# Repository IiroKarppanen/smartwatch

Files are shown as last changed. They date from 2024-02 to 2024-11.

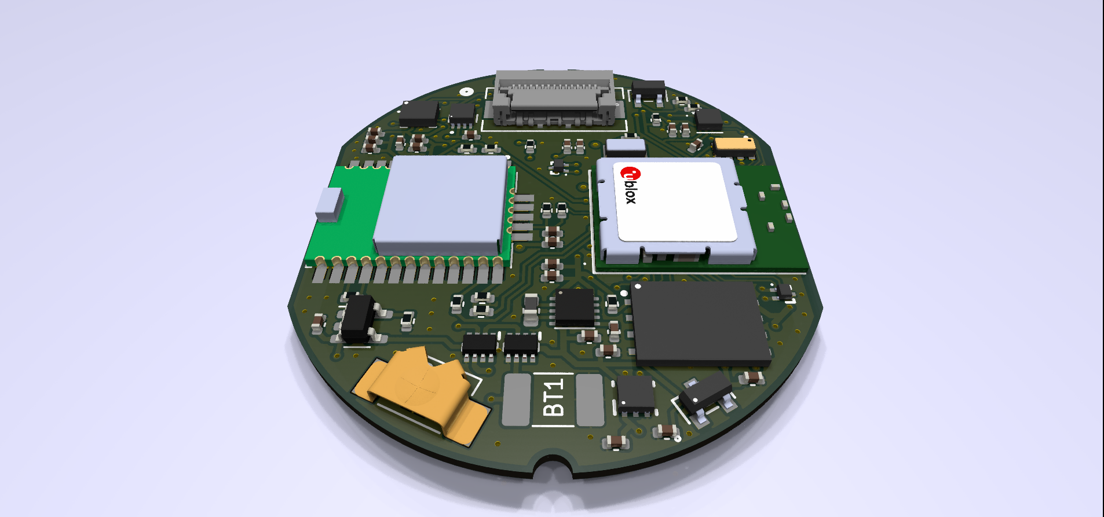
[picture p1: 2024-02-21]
Hardware/docs/render.png

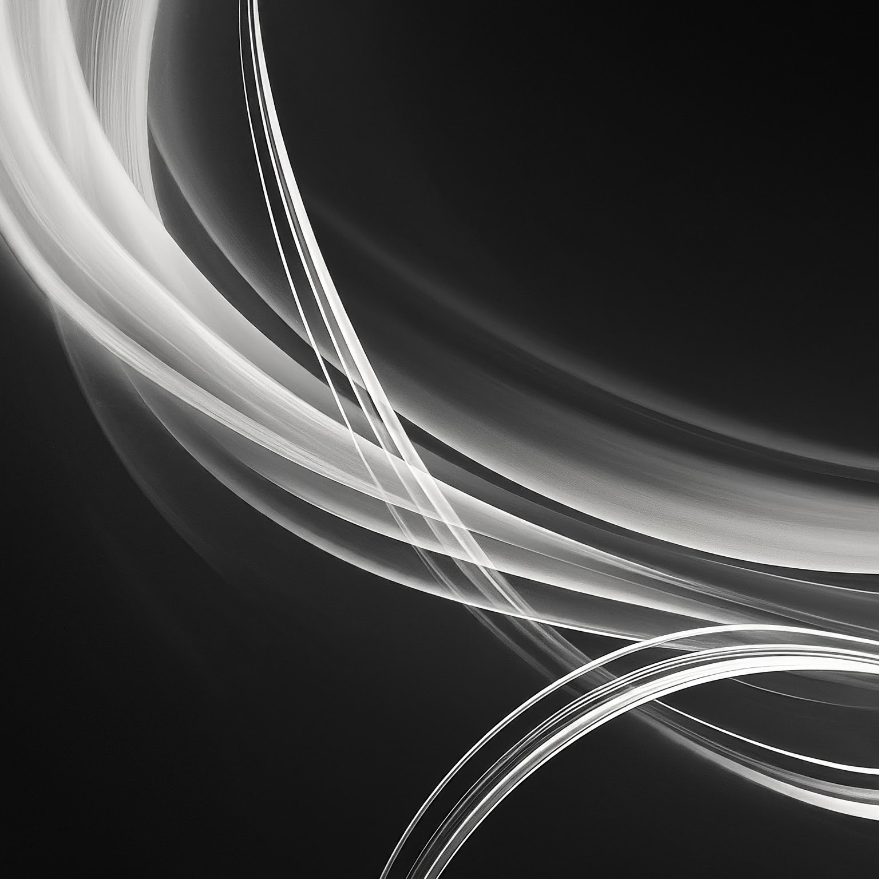
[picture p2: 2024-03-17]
Software/assets/image_fx_abstract_white_lines_over_black_background.jpg

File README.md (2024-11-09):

## Features
- nRF5340 SoC
- 240x240 LCD display
- Pulseoximetry
- GNSS
- Accelometer & Gyroscope
- Accurate RTC with backup battery

Näyttökuva 2024-11-07 140855

Näyttökuva 2024-11-07 140938

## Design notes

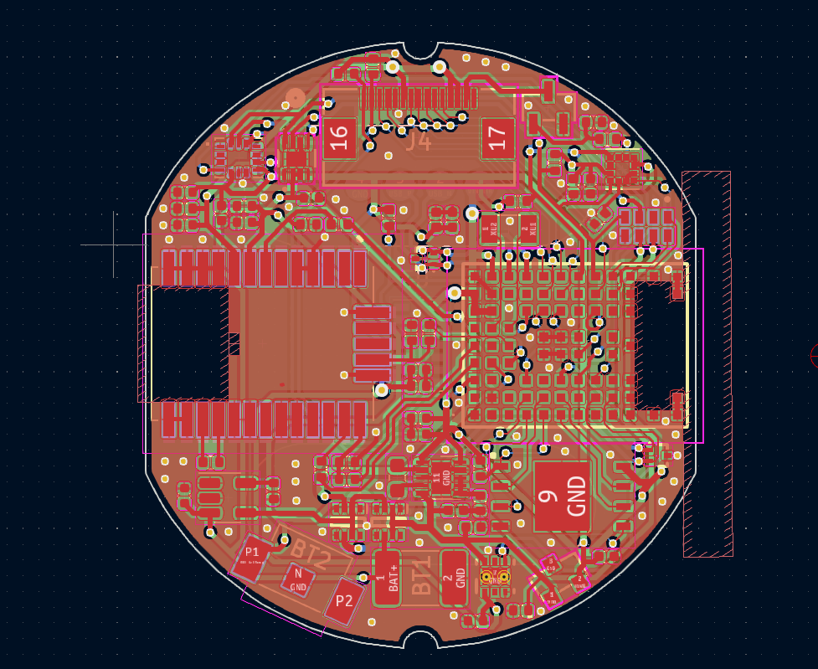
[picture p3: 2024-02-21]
Hardware/docs/pcb_view.png

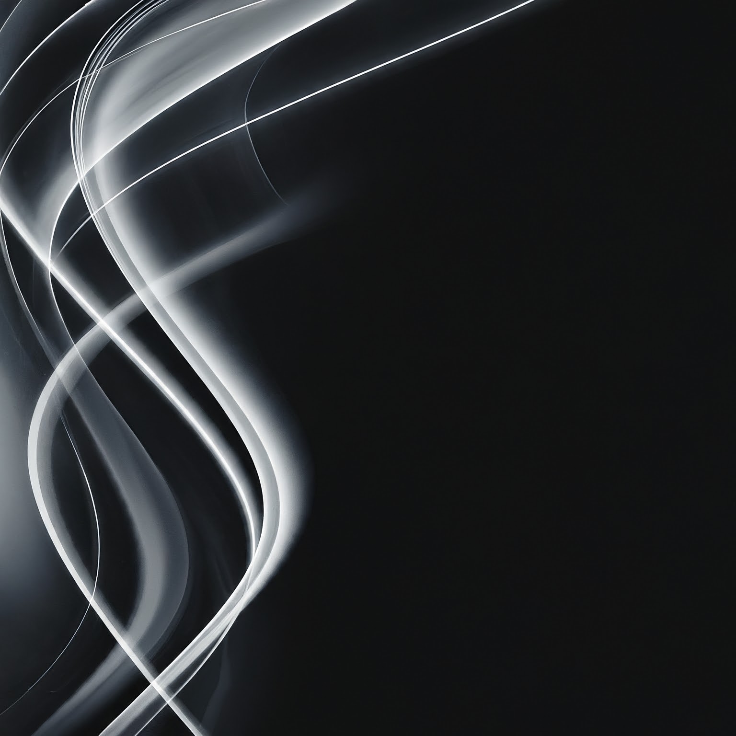
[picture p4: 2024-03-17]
Software/assets/image_fx_abstract_white_lines_over_black_background (1).jpg

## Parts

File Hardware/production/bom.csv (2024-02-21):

Designator | Footprint | Quantity | Value | LCSC Part #
BT1 | 1812 | 1 | Battery_Cell
BT2 | BAT_2994TR | 1 | 2994TR
C1, C10, C4, C6, C9 | 0402 | 5 | 10uF
C11, C13, C14 | 0402 | 3 | 100n
C12 | 0402 | 1 | 220nF
C15, C17 | 0402 | 2 | 100nF
C16, C22, C23 | 0402 | 3 | 1uF
C18, C2, C5, C8 | 0402 | 4 | 0.1uF
C19, C20, C7 | 0402 | 3 | 4.7uF
C21 | 0402 | 1 | 2.2uF
C3 | 0402 | 1 | 10u
IC1 | SON127P800X600X80-9N-D | 1 | W25Q256JVEIQ
IC2 | NORAB12000B | 1 | NORA-B120-00B
IC3, IC4 | SOTFL50P160X60-8N | 2 | LM66200DRLR
J1, J2 | Pogo_Female_4Pin | 2 | Conn_01x04
J4 | CONN_X05A20L15T_XKB | 1 | X05A20L15T
L2 | 0603 | 1 | MBKK1608T1R5M
MOSFET1 | SOT-23TO-236_318-08_ONS | 1 | 2N7002
R1 | 0402 | 1 | 100k | NRF52840-QIAA-R
R10, R12, R15, R16, R9 | 0402 | 5 | 4.7k | NRF52840-QIAA-R
R11 | 0402 | 1 | 1M
R13, R4, R6, R7 | 0402 | 4 | 1k
R14, R5, R8 | 0402 | 3 | 5k6
R17 | 0402 | 1 | 5.1k
R18 | 0805 | 1 | 470
R2 | 0402 | 1 | 0R
R3 | 0402 | 1 | 10k
U1 | 21-0168E_T822-3_MXM | 1 | MAX17048G+T10
U10 | IC_RV-3028-C7_32.768KHZ_1PPM-TA-QC | 1 | RV-3028-C7_32.768KHZ_1PPM-TA-QC
U11 | SOT-23-5 | 1 | MCP73831T-2ACI/OT | MCP73831-2-OT
U12 | DRV0006A | 1 | TPS70950QDRVRQ1
U2, U9 | DRT0003A | 2 | TPD2EUSB30DRTR
U3 | MAX30101EFD_T | 1 | MAX30101EFD_T
U4 | WSON-10-1EP_2.5x2.5mm_P0.5mm_EP1.2x2mm | 1 | TPS63031DSK
U5 | XCVR_L96-M33 | 1 | L96-M33
U6 | SOT-23_DIO | 1 | AP7313-18SAG-7
U7 | XDCR_BMI270 | 1 | BMI270
U8 | PQFN50P200X200X70-12N | 1 | LIS2MDLTR
X2 | Crystal_SMD_3215-2Pin_3.2x1.5mm | 1 | 9HT10-32.768KBZC-T

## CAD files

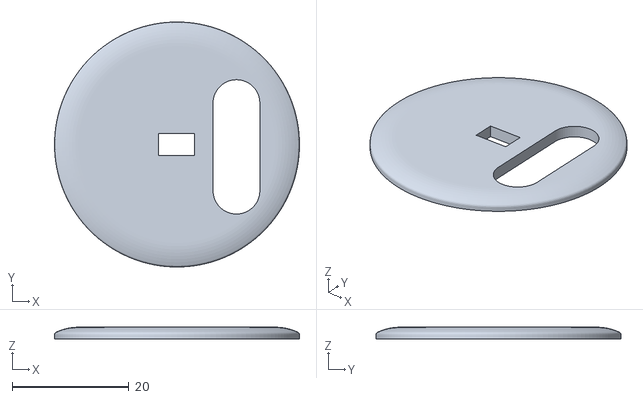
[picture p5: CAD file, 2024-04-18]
Hardware/docs/cover.stl
42.0 x 42.0 x 2.00

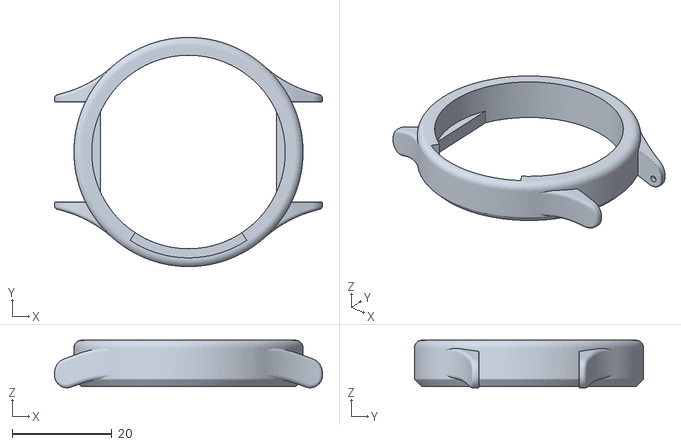
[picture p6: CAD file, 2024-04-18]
Hardware/docs/watch_S_holes.stl
53.8 x 46.0 x 9.57

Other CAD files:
Hardware/docs/watch_L_holes.stl

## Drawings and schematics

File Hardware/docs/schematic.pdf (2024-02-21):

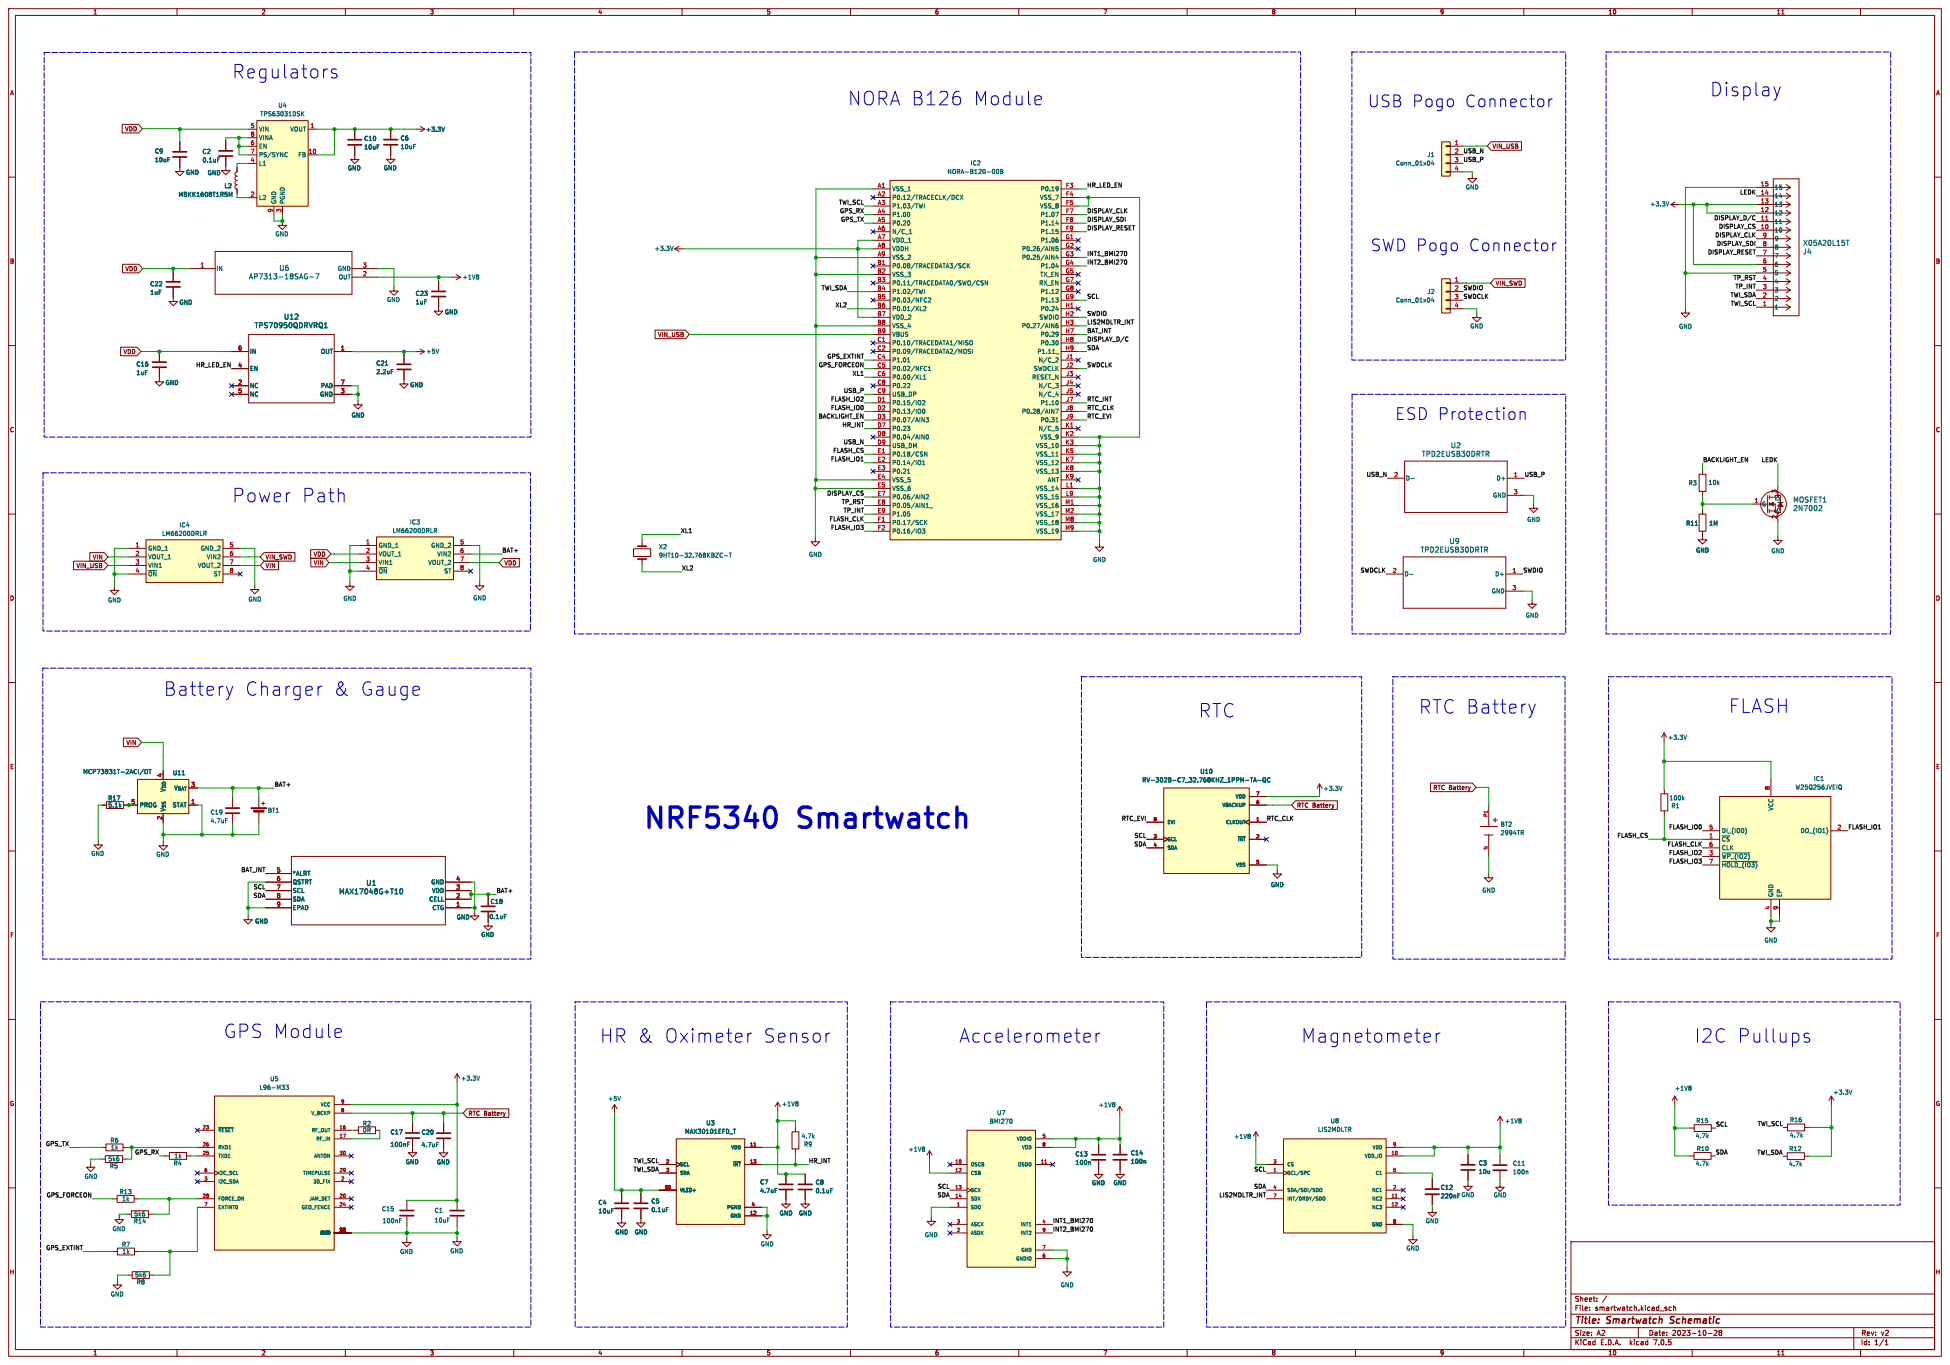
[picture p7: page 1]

NORA B126 Module
VSS_1 A1 P0.12/TRACECLK/DCX A2 P1.03/TWI A3 P1.00 A4 P0.20 A5 N/C_1 A6 VDD_1 A7 VDDH A8 VSS_2 A9 P0.08/TRACEDATA3/SCK B1 VSS_3 B2 P0.11/TRACEDATA0/SWO/CSN B3 P1.02/TWI B4 P0.03/NFC2 B5 P0.01/XL2 B6 VDD_2 B7 VSS_4 B8 VBUS B9 P0.10/TRACEDATA1/MISO C1 P0.09/TRACEDATA2/MOSI C2 P1.01 C4 P0.02/NFC1 C5 P0.00/XL1 C6 P0.22 C8 USB_DP C9 P0.15/IO2 D1 P0.13/IO0 D2 P0.07/AIN3 D3 P0.23 D7 P0.04/AIN0 D8 USB_DM D9 P0.18/CSN E1 P0.14/IO1 E2 P0.21 E3 VSS_5 E4 VSS_6 E5 P0.06/AIN2 E7 P0.05/AIN1_ E8 P1.05 E9 P0.17/SCK F1 P0.16/IO3 F2

File: smartwatch.kicad_sch Sheet: / GND

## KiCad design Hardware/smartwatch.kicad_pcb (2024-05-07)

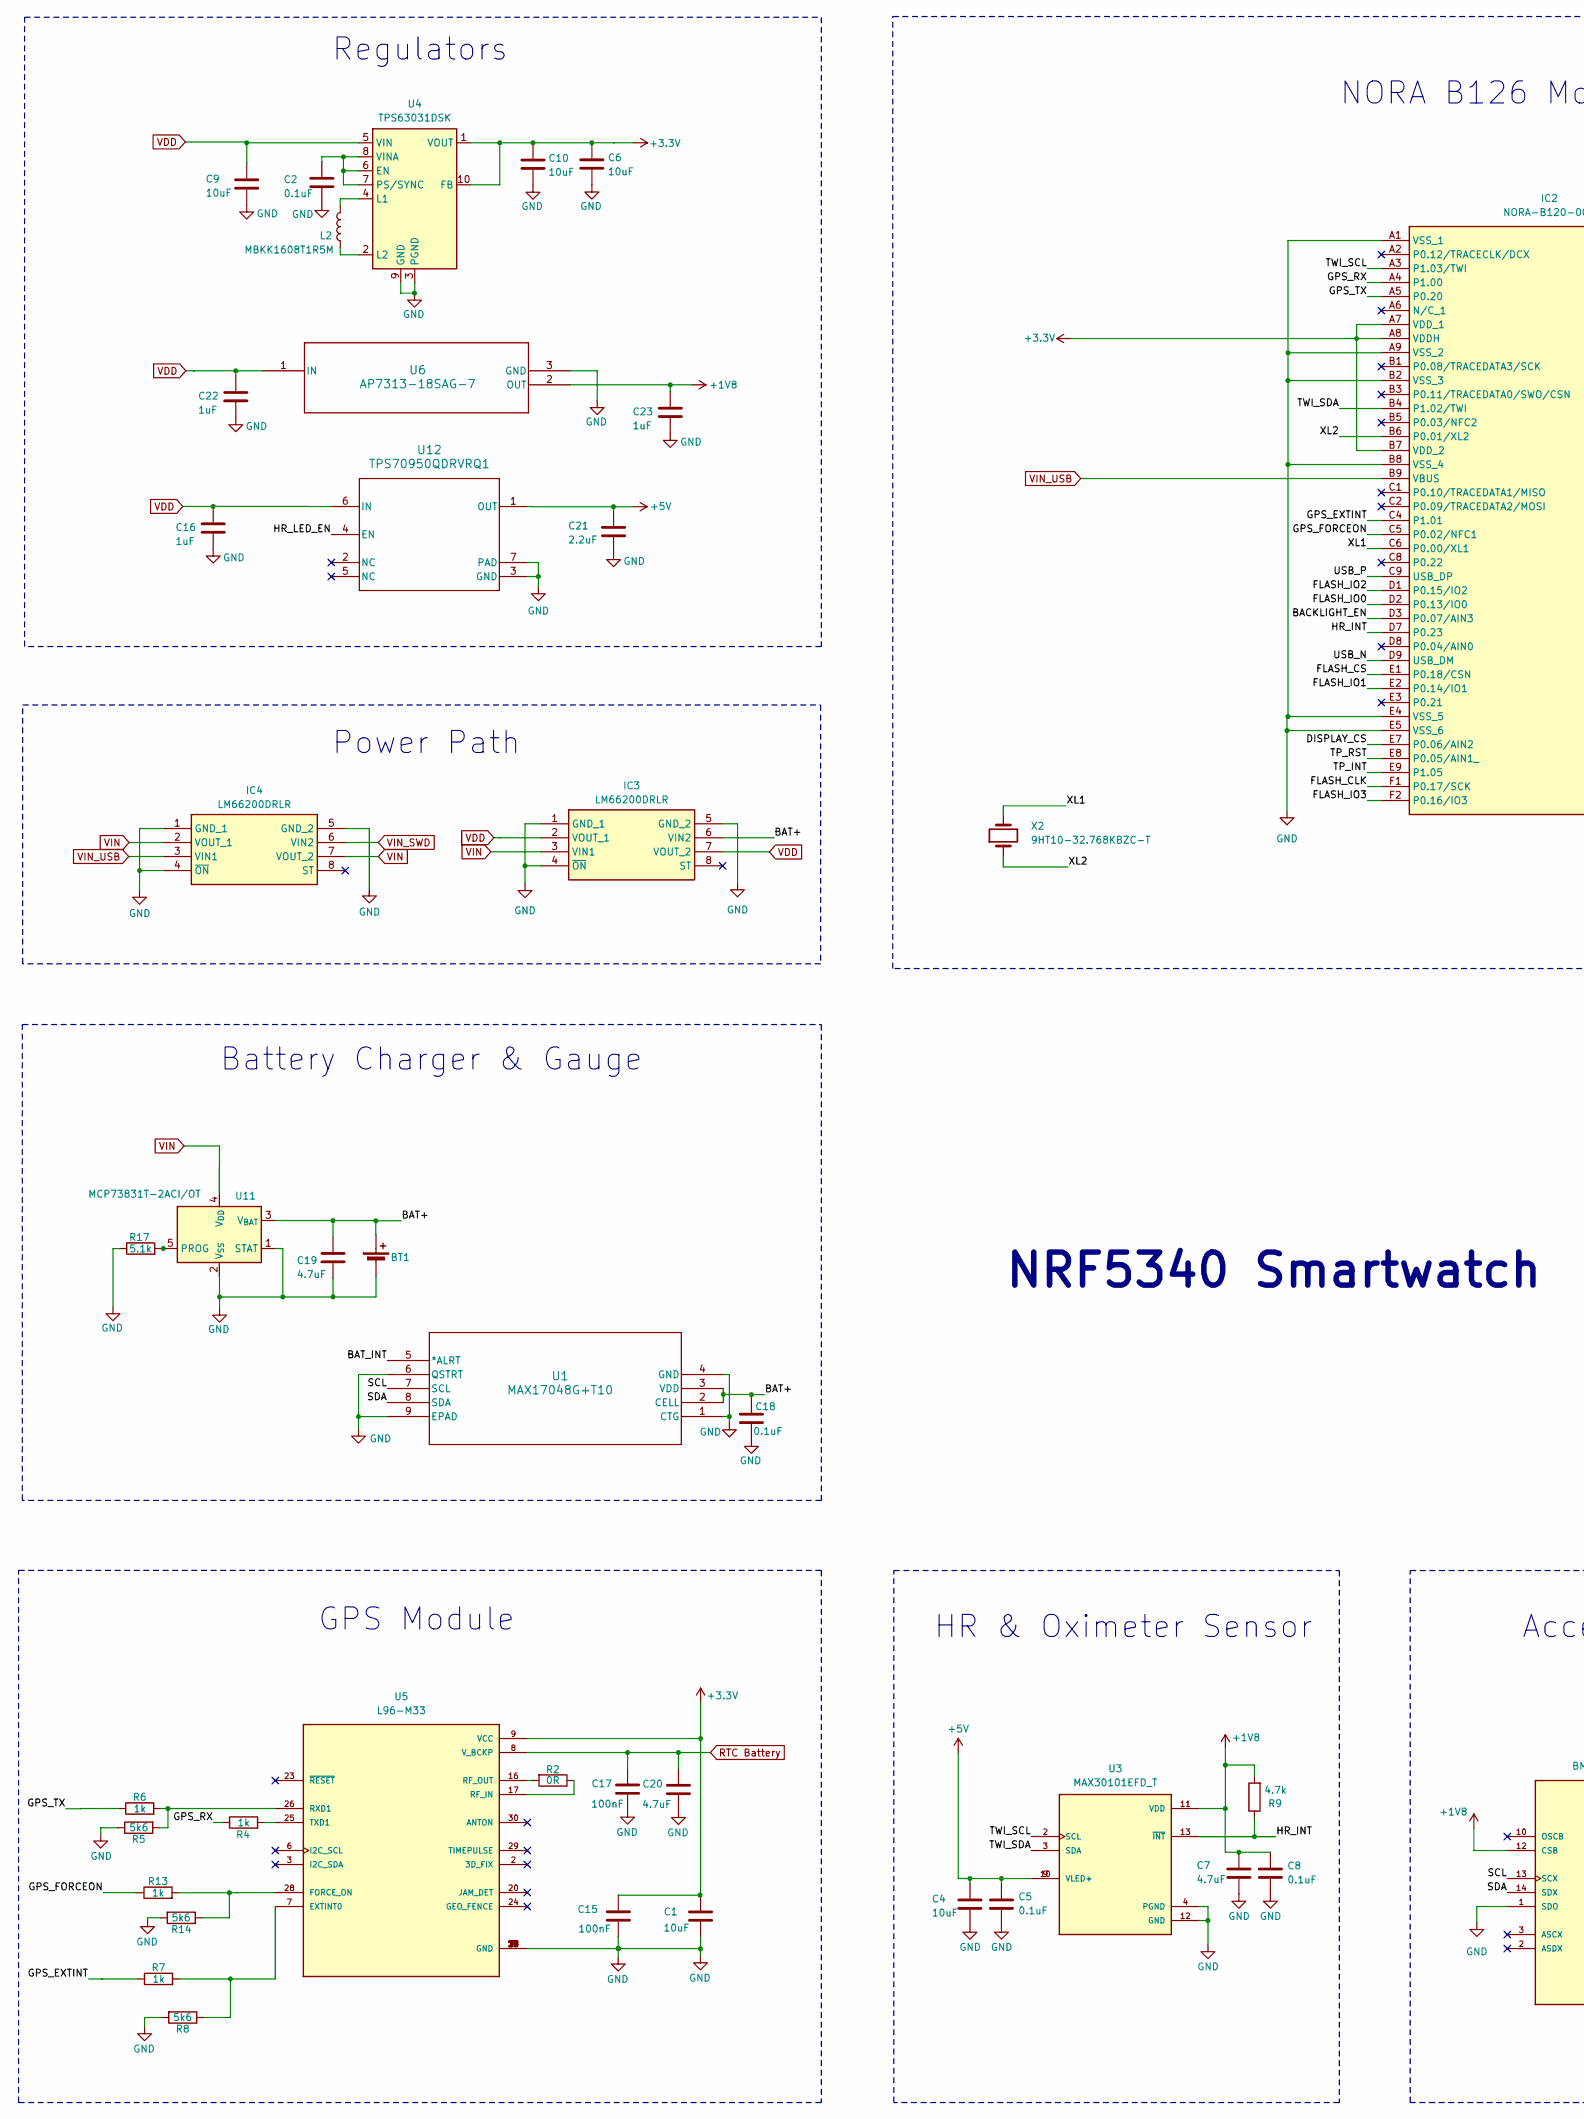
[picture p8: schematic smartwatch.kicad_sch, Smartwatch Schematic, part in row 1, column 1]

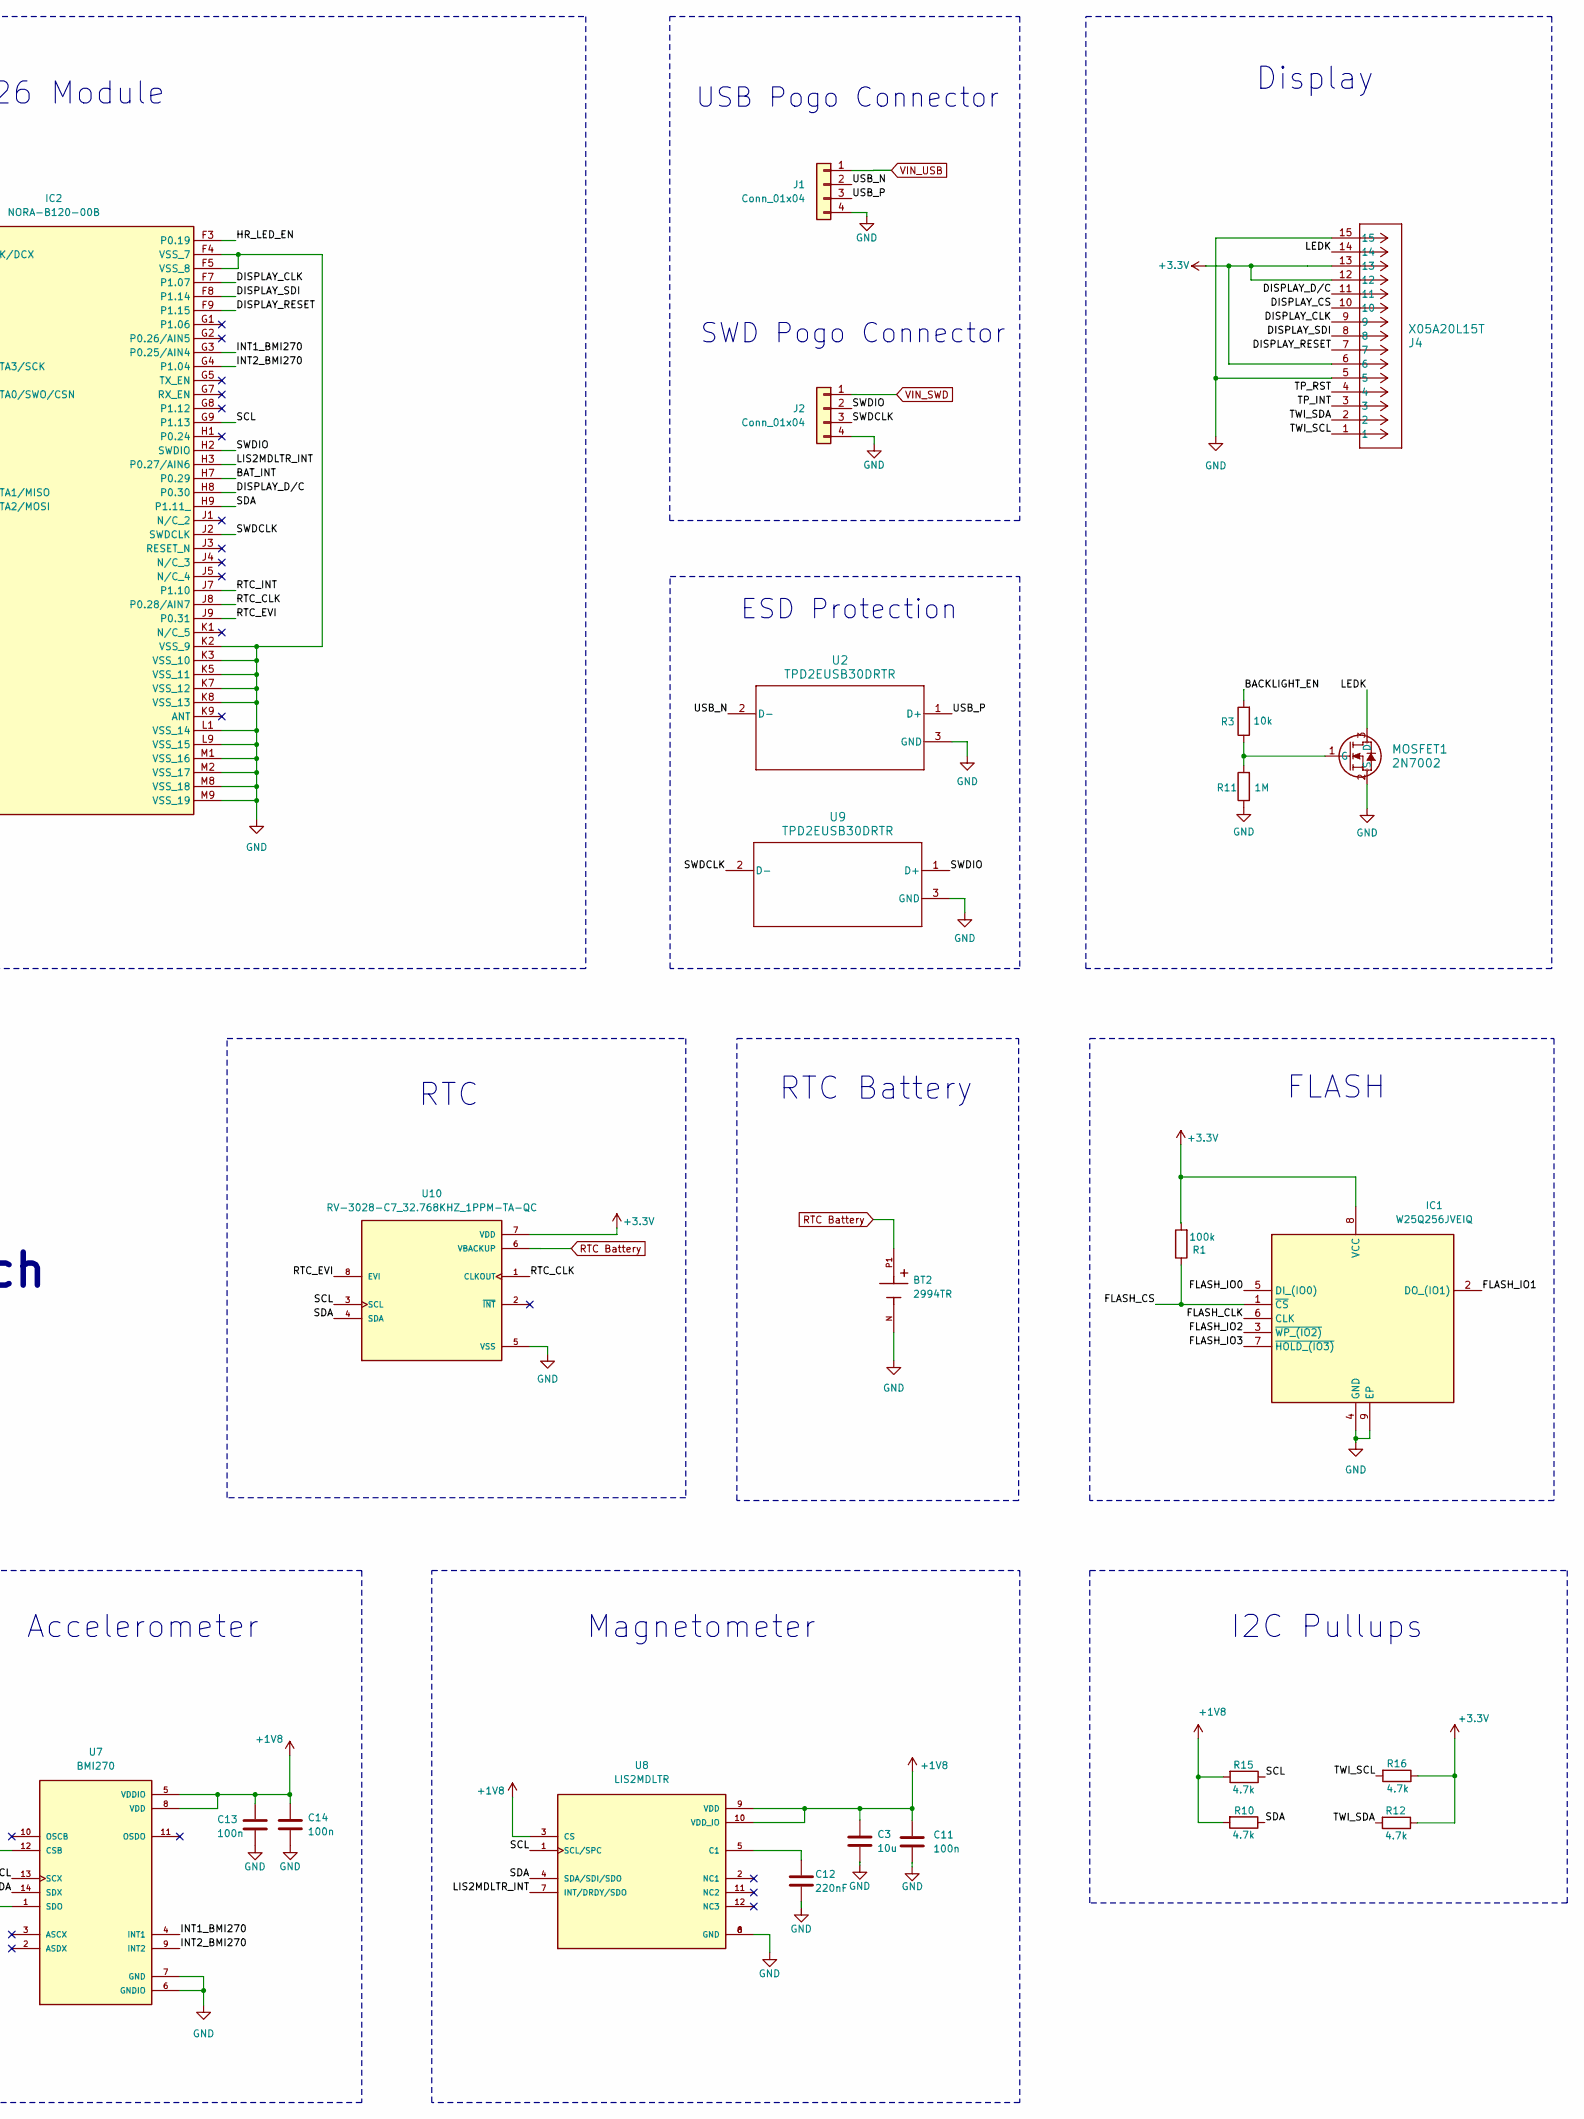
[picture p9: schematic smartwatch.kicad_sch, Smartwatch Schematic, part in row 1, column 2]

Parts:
BT1: Battery_Cell; C_1812_4532Metric_Pad1.57x3.40mm_HandSolder
BT2: 2994TR; BAT_2994TR; PARTREV E
C1, C4, C6, C9, C10: 10uF; C_0402_1005Metric
C2, C5, C8, C18: 0.1uF; C_0402_1005Metric
C3: 10u; C_0402_1005Metric
C7, C19, C20: 4.7uF; C_0402_1005Metric
C11, C13, C14: 100n; C_0402_1005Metric
C12: 220nF; C_0402_1005Metric
C15, C17: 100nF; C_0402_1005Metric
C16, C22, C23: 1uF; C_0402_1005Metric
C21: 2.2uF; C_0402_1005Metric
IC1: W25Q256JVEIQ; SON127P800X600X80-9N-D; Mouser Part Number 454-W25N01GVZEIGTR
IC2: NORA-B120-00B; NORAB12000B; Mouser Part Number 377-NORA-B120-00B
IC3, IC4: LM66200DRLR; SOTFL50P160X60-8N; Mouser Part Number 595-LM66200DRLR
J1, J2: Conn_01x04; Pogo_Female_4Pin
J4: X05A20L15T; CONN_X05A20L15T_XKB
L2: MBKK1608T1R5M; L_0603_1608Metric
MOSFET1: 2N7002; SOT-23TO-236_318-08_ONS
R1: 100k; R_0402_1005Metric; MPN NRF52840-QIAA-R
R2: 0R; R_0402_1005Metric
R3: 10k; R_0402_1005Metric
R4, R6, R7, R13: 1k; R_0402_1005Metric
R5, R8, R14: 5k6; R_0402_1005Metric
R9, R10, R12, R15, R16: 4.7k; R_0402_1005Metric; MPN NRF52840-QIAA-R
R11: 1M; R_0402_1005Metric
R17: 5.1k; R_0402_1005Metric
U1: MAX17048G+T10; 21-0168E_T822-3_MXM
U2, U9: TPD2EUSB30DRTR; DRT0003A
U3: MAX30101EFD_T; PARTREV 2
U4: TPS63031DSK; WSON-10-1EP_2.5x2.5mm_P0.5mm_EP1.2x2mm
U5: L96-M33; XCVR_L96-M33; DigiKey_Part_Number 2958-L96-M33TR-ND
U6: AP7313-18SAG-7; SOT-23_DIO
U7: BMI270; XDCR_BMI270
U8: LIS2MDLTR; PQFN50P200X200X70-12N; PARTREV Rev 5
U10: RV-3028-C7_32.768KHZ_1PPM-TA-QC; IC_RV-3028-C7_32.768KHZ_1PPM-TA-QC; PARTREV 1.3
U11: MCP73831T-2ACI/OT; SOT-23-5; MPN MCP73831-2-OT
U12: TPS70950QDRVRQ1; DRV0006A
X2: 9HT10-32.768KBZC-T; Crystal_SMD_3215-2Pin_3.2x1.5mm

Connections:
+1V8: C3.1, C7.1, C8.1, C11.1, C13.1, C14.1, C23.1, R9.2, R10.2, R15.2, U3.11 (VDD), U6.2 (OUT), U7.5 (VDDIO), U7.8 (VDD), U7.12 (CSB), U8.3 (CS), U8.9 (VDD), U8.10 (VDD_IO)
+3.3V: C1.1, C6.1, C10.1, C15.1, IC1.8 (VCC), IC2.A7 (VDD_1), IC2.A8 (VDDH), IC2.B7 (VDD_2), J4.6, J4.12, J4.13, R1.2, R12.1, R16.1, U4.1 (VOUT), U4.10 (FB), U5.9 (VCC), U10.7 (VDD)
+5V: C4.1, C5.1, C21.1, U3.9 (VLED+), U3.10 (VLED+), U12.1 (OUT)
/BACKLIGHT_EN: IC2.D3 (P0.07/AIN3), R3.2
/BAT+: BT1.1 (+), C18.1, C19.1, IC3.6 (VIN2), U1.2 (CELL), U1.3 (VDD), U11.3 (V_{BAT})
/BAT_INT: IC2.H7 (P0.29), U1.5 (*ALRT)
/DISPLAY_CLK: IC2.F7 (P1.07), J4.9
/DISPLAY_CS: IC2.E7 (P0.06/AIN2), J4.10
/DISPLAY_D/C: IC2.H8 (P0.30), J4.11
/DISPLAY_RESET: IC2.F9 (P1.15), J4.7
/DISPLAY_SDI: IC2.F8 (P1.14), J4.8
/FLASH_CLK: IC1.6 (CLK), IC2.F1 (P0.17/SCK)
/FLASH_CS: IC1.1 (~CS), IC2.E1 (P0.18/CSN), R1.1
/FLASH_IO0: IC1.5 (DI_(IO0)), IC2.D2 (P0.13/IO0)
/FLASH_IO1: IC1.2 (DO_(IO1)), IC2.E2 (P0.14/IO1)
/FLASH_IO2: IC1.3 (~WP_(IO2)), IC2.D1 (P0.15/IO2)
/FLASH_IO3: IC1.7 (~HOLD_(IO3)), IC2.F2 (P0.16/IO3)
/GPS_EXTINT: IC2.C4 (P1.01), R7.1
/GPS_FORCEON: IC2.C5 (P0.02/NFC1), R13.1
/GPS_RX: IC2.A4 (P1.00), R4.1
/GPS_TX: IC2.A5 (P0.20), R6.1
/HR_INT: IC2.D7 (P0.23), R9.1, U3.13 (~INT)
/HR_LED_EN: IC2.F3 (P0.19), U12.4 (EN)
/INT1_BMI270: IC2.G3 (P0.25/AIN4), U7.4 (INT1)
/INT2_BMI270: IC2.G4 (P1.04), U7.9 (INT2)
/LEDK: J4.14, MOSFET1.3 (D)
/LIS2MDLTR_INT: IC2.H3 (P0.27/AIN6), U8.7 (INT/DRDY/SDO)
/RTC_CLK: IC2.J8 (P0.28/AIN7), U10.1 (CLKOUT)
/RTC_EVI: IC2.J9 (P0.31), U10.8 (EVI)
/RTC_INT: IC2.J7 (P1.10)
/SCL: IC2.G9 (P1.13), R15.1, U1.7 (SCL), U7.13 (SCX), U8.1 (SCL/SPC), U10.3 (SCL)
/SDA: IC2.H9 (P1.11_), R10.1, U1.8 (SDA), U7.14 (SDX), U8.4 (SDA/SDI/SDO), U10.4 (SDA)
/SWDCLK: IC2.J2 (SWDCLK), J2.3, U9.2 (D-)
/SWDIO: IC2.H2 (SWDIO), J2.2, U9.1 (D+)
/TP_INT: IC2.E9 (P1.05), J4.3
/TP_RST: IC2.E8 (P0.05/AIN1_), J4.4
/TWI_SCL: IC2.A3 (P1.03/TWI), J4.1, R16.2, U3.2 (SCL)
/TWI_SDA: IC2.B4 (P1.02/TWI), J4.2, R12.2, U3.3 (SDA)
/USB_N: IC2.D9 (USB_DM), J1.2, U2.2 (D-)
/USB_P: IC2.C9 (USB_DP), J1.3, U2.1 (D+)
/XL1: IC2.C6 (P0.00/XL1), X2.2
/XL2: IC2.B6 (P0.01/XL2), X2.1
unnamed: MOSFET1.1 (G), R3.1, R11.2
unnamed: C2.1, U4.6 (EN), U4.7 (PS/SYNC), U4.8 (VINA)
unnamed: L2.2, U4.4 (L1)
unnamed: L2.1, U4.2 (L2)
unnamed: R13.2, R14.1, U5.28 (FORCE_ON)
unnamed: R2.1, U5.17 (RF_IN)
unnamed: R2.2, U5.16 (RF_OUT)
unnamed: R5.2, R6.2, U5.26 (RXD1)
unnamed: R4.2, U5.25 (TXD1)
unnamed: C12.1, U8.5 (C1)
unnamed: R17.2, U11.5 (PROG)
RTC Battery: BT2.P1, C17.1, C20.1, U5.8 (V_BCKP), U10.6 (VBACKUP)
VDD: C9.1, C16.1, C22.1, IC3.2 (VOUT_1), IC3.7 (VOUT_2), U4.5 (VIN), U6.1 (IN), U12.6 (IN)
VIN: IC3.3 (VIN1), IC4.2 (VOUT_1), IC4.7 (VOUT_2), U11.4 (V_{DD})
VIN_SWD: IC4.6 (VIN2), J2.1
VIN_USB: IC2.B9 (VBUS), IC4.3 (VIN1), J1.1

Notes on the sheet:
NORA B126 Module
NRF5340 Smartwatch
HR & Oximeter Sensor
Magnetometer
GPS Module
I2C Pullups
SWD Pogo Connector
RTC Battery
Battery Charger & Gauge
Display
Accelerometer
USB Pogo Connector
ESD Protection
FLASH
Power Path
RTC
Regulators

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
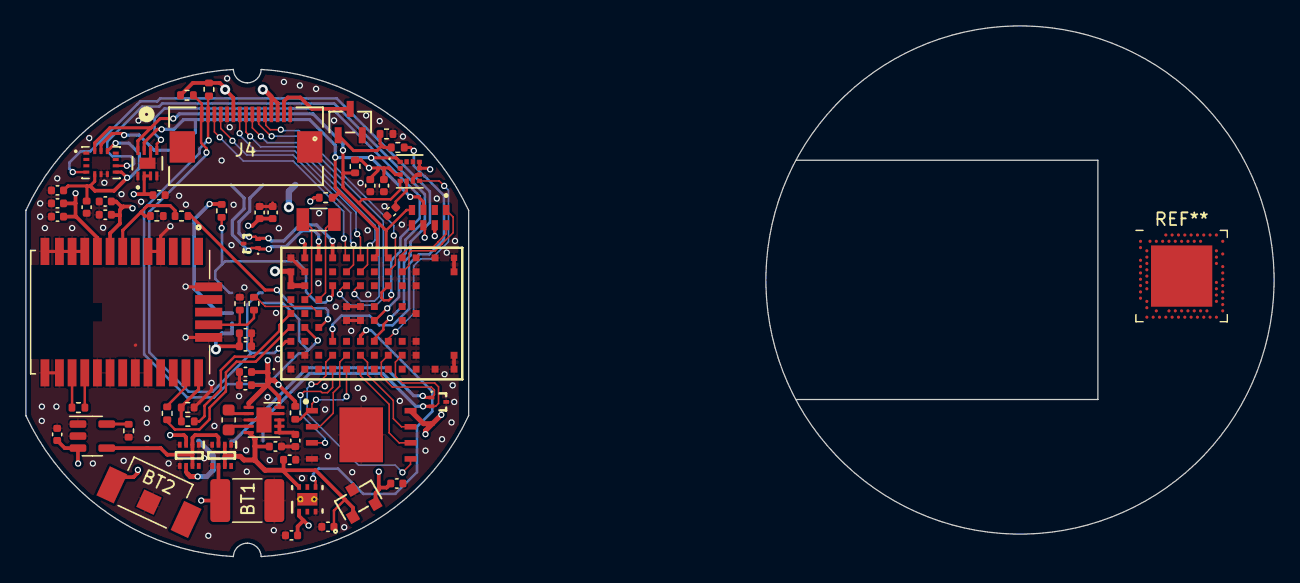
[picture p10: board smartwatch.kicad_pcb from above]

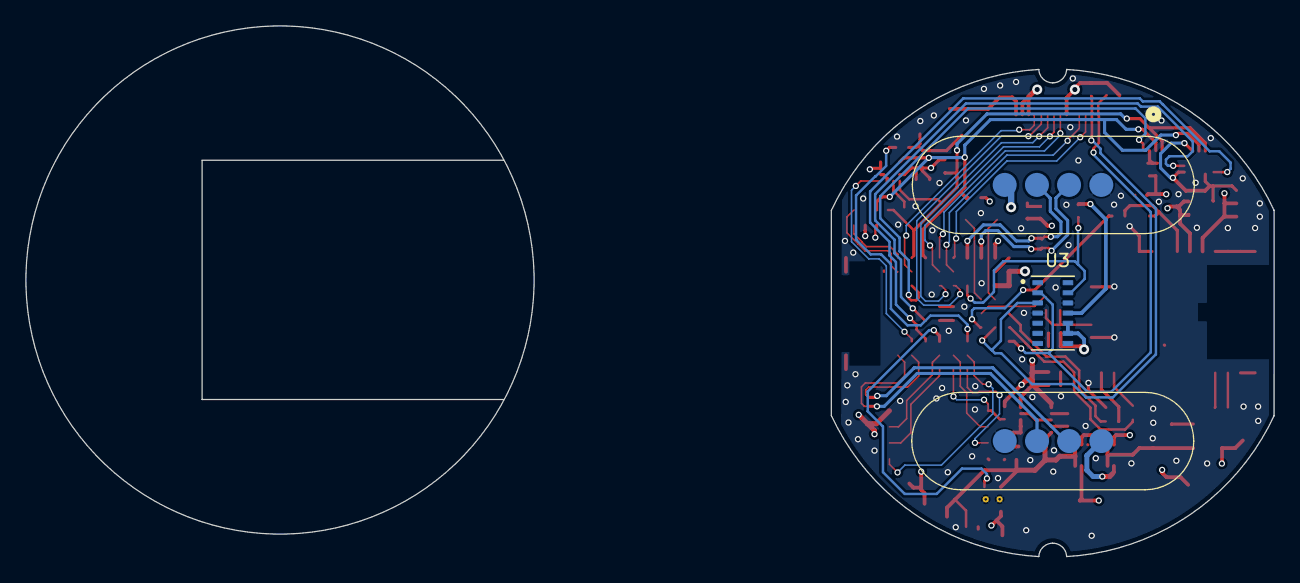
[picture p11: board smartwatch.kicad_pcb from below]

Board: 4 copper layers, 35.0 x 38.5 mm, 64 parts (3 on the bottom side), 59 nets.

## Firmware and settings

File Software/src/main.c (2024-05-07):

#include <zephyr/kernel.h>
#include <zephyr/kernel/thread_stack.h>
#include <stdio.h>
#include <stdint.h>
#include <string.h>
#include <zephyr/sys/printk.h>
#include <SEGGER_RTT.h>
#include <zephyr/drivers/sensor.h>
#include <zephyr/device.h>
#include <zephyr/devicetree.h>
#include <zephyr/drivers/i2c.h>
#include <zephyr/drivers/gpio.h>
#include <zephyr/input/input.h>
#include <zephyr/drivers/pwm.h>
#include <zephyr/drivers/uart.h>
#include <lvgl.h>
#include <ui.h>
#include <nrfx_clock.h>



#define LOG_LEVEL CONFIG_LOG_DEFAULT_LEVEL
#include <zephyr/logging/log.h>
LOG_MODULE_REGISTER(app);


#define LVGL_THREAD_STACK_SIZE 8192
#define LVGL_THREAD_PRIORITY 1

// LVGL thread
K_THREAD_STACK_DEFINE(lvgl_thread_stack, LVGL_THREAD_STACK_SIZE);
struct k_thread lvgl_thread_data;


static bool lvgl_task_enabled = true;

// LVGL task
void lvgl_task(void *p1, void *p2, void *p3)
{
    while (1) {
        if (lvgl_task_enabled) {
            lv_task_handler();
        }
        k_msleep(50);  
    }
}


#define I2C_SLAVE_ADDR_MIN 0x15  // Minimum 7-bit I2C address
#define I2C_SLAVE_ADDR_MAX 0x99  // Maximum 7-bit I2C address

void i2c_scan(void) {
    struct device *i2c_dev;
    int error;
	int count = 0;

    // Get the I2C device
	// device_get_binding("UART_0");
    i2c_dev = DEVICE_DT_GET(DT_NODELABEL(i2c2));
    if (!i2c_dev) {
        printk("Could not find I2C device\n");
        return;
    }

    printk("Scanning I2C bus for devices...\n");

    // Iterate over possible 7-bit I2C addresses (0x08 to 0x77)
    for (int addr = I2C_SLAVE_ADDR_MIN; addr <= I2C_SLAVE_ADDR_MAX; addr++) {
        uint8_t reg_addr = 0x00;  // Register address to read (dummy for probing)
        uint8_t rx_data;          // Data read (dummy for probing)

        // Perform a burst read from a register address (0x00) at the device address
        error = i2c_burst_read(i2c_dev, addr, reg_addr, &rx_data, 1);
        if (error == 0) {
            printk("Found device at address 0x%02X\n", addr);
			count++;
        }
		else if (error != -ENODEV) {
            // Print error only if it's not "device not present" (-ENODEV)
        }
    }

    printk("I2C scanning complete\n");
	printk("Amount of devices: %d\n", count);
}






void main(void){



	SEGGER_RTT_Init();
	printk("RTT LOG\n\n");
    k_sleep(K_SECONDS(3));


	// NRF_CLOCK_HFCLK_DIV_1 - 128Mhz
	// NRF_CLOCK_HFCLK_DIV_2 - 64Mhz
	// NRF_CLOCK_HFCLK_DIV_4 - 32Mhz
	nrfx_clock_divider_set(NRF_CLOCK_DOMAIN_HFCLK, NRF_CLOCK_HFCLK_DIV_1);

	const struct device *display_dev = DEVICE_DT_GET(DT_CHOSEN(zephyr_display));

	if (!device_is_ready(display_dev))
	{
		printk("Display not ready\n");
		return;
	}

	
	// Initialize LVGL
    lv_init();
	ui_init();

    k_thread_create(&lvgl_thread_data, lvgl_thread_stack,
        K_THREAD_STACK_SIZEOF(lvgl_thread_stack),
        lvgl_task, NULL, NULL, NULL,
        LVGL_THREAD_PRIORITY, 0, K_NO_WAIT);



	//i2c_scan();


	while (1) {
	

		printk("-\n");
		k_sleep(K_MSEC(1000));
	
	}
    
}

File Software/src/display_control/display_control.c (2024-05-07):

#include <zephyr/kernel.h>
#include <zephyr/kernel/thread_stack.h>
#include <stdio.h>
#include <stdint.h>
#include <string.h>
#include <zephyr/sys/printk.h>
#include <SEGGER_RTT.h>
#include <zephyr/drivers/sensor.h>
#include <zephyr/device.h>
#include <zephyr/devicetree.h>
#include <zephyr/drivers/i2c.h>
#include <zephyr/drivers/gpio.h>
#include <zephyr/input/input.h>
#include <zephyr/drivers/pwm.h>
#include <zephyr/sys/util.h>
#include <zephyr/drivers/display.h>

#include "../sensor_data/inertial_measurement.h"

#define ZEPHYR_USER_NODE DT_PATH(zephyr_user)

#define DISPLAY_ON_TIME 8000 // Time display stays on after last trigger event

static bool lvgl_task_enabled = true;
static bool backlight_is_on = true;

const struct device *display_dev;
const struct gpio_dt_spec backlight_en = GPIO_DT_SPEC_GET(ZEPHYR_USER_NODE, bl_gpios);




K_TIMER_DEFINE(display_timer, NULL, NULL);
uint32_t last_expiration_time = 0;

void display_timer_handler(struct k_timer *timer)
{
	last_expiration_time = k_uptime_get_32();

    backlight_is_on = false;
    gpio_pin_set_dt(&backlight_en, 0);
	display_blanking_on(display_dev);
}

void reset_timer(void)
{
    k_timer_stop(&display_timer);
    last_expiration_time = 0;
}

void restart_timer(void)
{
    // Calculate the remaining time to the next expiration
    uint32_t current_time = k_uptime_get_32();
    uint32_t remaining_time = last_expiration_time > 0 ? (15000 - (current_time - last_expiration_time)) : 15000;

    // Start the timer with the remaining time
    k_timer_start(&display_timer, K_MSEC(remaining_time), K_MSEC(15000));
    printk("Timer restarted with %u ms remaining\n", remaining_time);
}





#define DISPLAY_CONTROL_THREAD_STACK_SIZE 4096
#define DISPLAY_CONTROL_THREAD_PRIORITY 5

// LVGL thread
K_THREAD_STACK_DEFINE(display_control_thread_stack, DISPLAY_CONTROL_THREAD_STACK_SIZE);
struct k_thread display_control_thread_data;



void display_control_task()
{
    while (1) {
        
		if(acc[1].val1 == -7 || acc[1].val1 == -8 || acc[1].val1 == -9 || acc[1].val1 == -10){

			reset_timer();
    		restart_timer();

			if(!backlight_is_on){
				display_blanking_off(display_dev);
				gpio_pin_set_dt(&backlight_en, 1);
				backlight_is_on = true;
			}
		
		}
        
        k_msleep(100);  
		
    }
}







void reset_display_timer(){
	gpio_pin_set_dt(&backlight_en, 1);
	reset_timer();
	restart_timer();
}



void init_display_control(){

    // Turn on display backlight
    gpio_pin_configure_dt(&backlight_en, GPIO_OUTPUT_HIGH);
	gpio_pin_set_dt(&backlight_en, 1);

    display_dev = DEVICE_DT_GET(DT_CHOSEN(zephyr_display));

	if (!device_is_ready(display_dev))
	{
		printk("Display not ready\n");
		return;
	}


    k_timer_init(&display_timer, display_timer_handler, NULL);
    k_timer_start(&display_timer, K_MSEC(DISPLAY_ON_TIME), K_MSEC(DISPLAY_ON_TIME));

    k_thread_create(&display_control_thread_data, display_control_thread_stack,
    K_THREAD_STACK_SIZEOF(display_control_thread_stack),
    display_control_task, NULL, NULL, NULL,
    DISPLAY_CONTROL_THREAD_PRIORITY, 0, K_NO_WAIT);

}


SYS_INIT(init_display_control, APPLICATION, CONFIG_SENSOR_INIT_PRIORITY);




// Turn display on
//if(backlight_status == 1){
//	reset_display_timer();
//}

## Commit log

2023-10-04 pcb layout almost complete
    [smartwatch.kicad_pcb, smartwatch.kicad_sch]
2023-10-08 pcb complete
    [smartwatch.kicad_pcb, smartwatch.kicad_sch]
2023-10-28 changed gps module
    [bom.csv, designators.csv, positions.csv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]
2023-10-28 New rtc module
    [smartwatch.kicad_pcb, smartwatch.kicad_sch]
2023-10-31 changed to nrf5340 & did some rework to charging circuit
    [bom.csv, designators.csv, positions.csv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]
2023-11-03 added battery gauge
    [smartwatch.kicad_pcb, smartwatch.kicad_sch]
2023-11-03 charging circuit complete
    [smartwatch.kicad_pcb, smartwatch.kicad_sch]
2023-11-06 switched to 4 layers
    [bom.csv, designators.csv, positions.csv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]
2023-11-06 changed backlight resistor values
    [smartwatch.kicad_sch]
2023-11-06 worked on power traces & added mounting holes
    [smartwatch.kicad_pcb, smartwatch.kicad_sch]
2023-11-10 added lm66200
    [smartwatch.kicad_pcb, smartwatch.kicad_sch]
2023-11-13 signal routing 50% complete
    [smartwatch.kicad_pcb, smartwatch.kicad_sch]
2023-11-15 ready for production
    [bom.csv, designators.csv, positions.csv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]
2023-11-15 update 1
    [bom.csv, designators.csv, positions.csv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]
2023-12-25 v3 schema complete
    [BMI270.step, smartwatch.kicad_sch]
2024-01-02 changed gps moduleto l96
    [bom.csv, designators.csv, positions.csv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]
2024-01-07 added rtc
    [smartwatch.kicad_pcb, smartwatch.kicad_sch]
2024-02-09 final version
    [bom.csv, designators.csv, positions.csv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]
2024-02-21 progress on display driver
2024-04-18 implemented uart communication with gnss module
